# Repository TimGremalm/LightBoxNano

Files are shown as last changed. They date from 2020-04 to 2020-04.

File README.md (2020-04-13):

# LightBoxNano
a generic LED controller that can be populated for either RGBW LED strip or addressable LED strip like WS2812.

It has the option for populating a pair of potentiometer, and a 5 way slider switch for controlling light modes.

An Arduino Nano is mounted using ordinary 2.54mm pitch pin headers.
Optionally a ESP32 Pico Kit can be mounted instead of the Nano, this is much more expensive it is a more powerful MCU and have WiFi.

A RS485 receiver and a pair of XLR connectors can also transform the LED controller into a DMX driver.

# Power Supply and voltage rails
## Input rail
The input voltage to LightBoxNano are called VIN and can range from 5 to 30V.
Make sure to only feed LightBoxNano with a voltage that the LED strip can handle. The maximum voltage is limited by the maximum voltage of the IRLML6344 Mosfets and of what the LED strip can handle.

If using 5V on Vin you need to read "Logic rail" to populate it correctly.

## RGBW rail
The positive rail for the LED strip driver is directly fed from VIN, it's usually 12V.

## Addressable rail
The positive rail for the addressable LED strip driver is directly fed from VIN, it's usually 5V.

## Logic rail
The logic rail should be 5V and feed the micro controller.

There is 2 options for the logic rail:
* Use buck, when Vin is greater than 5.5V.
* Use direct jumper link when Vin is 5V.

Note that the logic rail bypasses Vin_fused.

The buck converter using TI's guide:
https://webench.ti.com/power-designer/switching-regulator/select

https://webench.ti.com/appinfo/webench/scripts/SDP.cgi?ID=572687AF787DDED1

## Protection circuit
There is 2 options for input protection:
* A classic fuse
* Highside High Current Power Switch

### Classic Fuse
A much cheaper option then the high side switch, but one time use only.
Populate with a  appropriate 1206 fast blow fuse.
Example: Fuse Fast Blow 10A 1206 MCCFB1206TFF/10

No reverse polarity protection exist when using a classic fuse.

### Highside High Current Power Switch
The Infineon BTS50055-1TMC is a highside high current power switch with buildt in reverse
polarity and temperature protection.

It's also used to measure current consumption; Current_Feedback as analog output.
To enable the high power switch Enable_Vin_fused must be driven low.

Both Current_Feedback and Enable_Vin_fused goes to the MCU so it can act on over current
and act as a resettable fuse.

Vin_fused
| Channel			| Arduino Nano		| ESP32 |
| --- | --- | ----- |
| Current_Feedback	| A0 (PC0)			| IO38	|
| Enable_Vin_fused	| D13 (PB5)			| IO37	|

# RGBW driver
This is made for LED strip that have red, green, blue and white channels that have a common positive rail like +12V.
The LED driver can drive 4 output channels in constant voltage mode at 5A each. The channel can drive up to 10A current if an optional IRLML6344 is mounted.
One color channel on a 5m LED strip consisting of 300 LED's will draw 6A (20mA x 300px) when fully lit. A full RGB strip 18A, and a RGBW strip 24A.

| Channel	| Arduino Nano		| ESP32 |
| --- | --- | ----- |
| Red		| D5 (PD5)			| IO26	|
| Green		| D6 (PD6)			| IO27	|
| Blue		| D9 (PB1)			| IO13	|
| White		| D10 (PB2)			| IO15	|

# Addressable LED driver
Addressable LED strip is hooked up directly to VIN and the data pin is going to micro controller via a 1k resistor.

| Channel		| Arduino Nano		| ESP32 |
| --- | --- | ----- |
| Addressable	| D3 (PD3)			| IO25	|

# Control interface
Two potentiometers can optionally be mounted. They are pulled up to 3.3V, so you won't get the full range on the Nano.
| Channel	| Arduino Nano		| ESP32 |
| --- | --- | ----- |
| POT_1		| A1 (PC1)			| IO26	|
| POT_2		| A2 (PC2)			| IO27	|

A 10 position rotary coded switch can optionally be mounted for selecting different modes.
| Channel	| Arduino Nano		| ESP32 |
| --- | --- | ----- |
| SwCode1	| D7 (PD7)			| IO14	|
| SwCode2	| D8 (PB0)			| IO12	|
| SwCode4	| D11 (PB3)			| IO2	|
| SwCode8	| D12 (PB4)			| IO4	|

10 position switch is coded in binary.
| Code	| 0	| 1	| 2	| 3	| 4	| 5	| 6	| 7	| 8	| 9	|
| ----- | -	| -	| -	| -	| -	| -	| -	| -	| -	| -	|
| 1		| 	| *	| 	| *	| 	| *	| 	| *	| 	| *	|
| 2		| 	| 	| *	| *	| 	| 	| *	| *	| 	| 	|
| 4		| 	| 	| 	| 	| *	| *	| *	| *	| 	| 	|
| 8		| 	| 	| 	| 	| 	| 	| 	| 	| *	| *	|

Also a pin header of the Arduino Nano will be easily assessable for hooking up random stuff.

# DMX Tranceiver
A RS-485 transceiver can optionally be mounted for sending and receiveing DMX512.
It uses ADM2687E which isolates the RS-485 bus from the low voltage micro controller side. This is important as electrical errors down the bus can propagage along the bus.
ADM2687E also isolates the power on the bus side by a buildt in DC to DC converter.

The tranceiver can be set to send DMX data if the jumper links "Link_DriverOutputA1" and "Link_DriverOutputB1" is soldered.

| Jumper							| Description													|
| --- | ---	|
| Link_DriverOutputA1				| Links the Z (Driver Inverting Output) to DMX+					|
| Link_DriverOutputB1				| Links the Y (Driver Noninverting Output) to DMX-				|
| Receiver_Disable1					| Pulls RE (Receiver Enable) to High which disables receiver	|
| Receiver_Enable1					| Pulls RE (Receiver Enable) to Low which enables receiver		|
| Driver_Enable1					| Pulls DE (Driver Enable) to High which enables sender			|
| Driver_Disable1					| Pulls DE (Driver Enable) to Low which disables sender			|
| Link_TransceiverGnd_To_DMXgnd1	| Links DMX bus Gnd to ADM2687E Gnd2							|
| Link_DMXgnd_To_DMXchassignd1		| Links DMX ground shield to ADM2687E Gnd2						|

DMX Send and Receive can be hooked up to UART channels on a MCU.
Receiver Enable and Driver Enable can also be driven by the micro controller (only ESP32).
| Channel			| Arduino Nano		| ESP32 |
| --- | --- | ----- |
| DMX_Send			| D1 TX (PD0)		| IO21	|
| DMX_Receive		| D0 RX (PD1)		| IO22	|
| DMX_ReceiveEnable	| N.C				| IO19	|
| DMX_DriveEnable	| N.C				| IO23	|

# MCU
An Arduino Nano V3 (ATmega328) is selected because it's cheap, available and have enough power for most applications.

Another option is to mount a ESP32 Pico Kit instead which is much more powerful and have built in WiFi.

# BOM (Bill Of Material)
| Amount	| Manufacturer		| Description										| Article Number		| URL																									|
| --- | --- | ---	| --- | --- |
| 1			| Arduino			| MCU Arduino Nano 3 ATmega328						| A000005				| https://se.farnell.com/arduino-org/a000005/arduino-nano-utv-rd-kort/dp/1848691						|
| 1			| Espressif			| MCU ESP32 Pico Kit V4								| ESP32-PICO-KIT		| https://www.digikey.com/product-detail/en/espressif-systems/ESP32-PICO-KIT/1904-1030-ND/9381703		|
| 8			| Infineon			| Mosfet N-Ch 5A SOT-23								| IRLML6344TRPBF		| https://se.farnell.com/infineon/irlml6344trpbf/mosfet-n-kan-30v-5a-sot23/dp/1857299					|
| 1			| Infineon			| Highside High Current Power Switch 34V 17A 6.0 mΩ	| BTS500551TMCATMA1		| https://se.farnell.com/infineon/bts500551tmcatma1/effektbelastning-h-s-34v-to-220/dp/2480566			|
| 1			| Analog Devices	| RS485 Transceiver Isolated						| ADM2687EBRIZ			| https://se.farnell.com/analog-devices/adm2687ebriz/transceiver-iso-rs485-16soic/dp/2008784			|
| 1			| Multicomp			| Fuse Fast Blow 10A 1206							| MCCFB1206TFF/10		| https://se.farnell.com/multicomp/mccfb1206tff-10/s-kring-ytmont-10a-snabb-1206/dp/2850011				|
| 1			| Littelfuse		| Schottky 200V 10A									| MBRD10200CT			| https://se.farnell.com/littelfuse/mbrd10200ct/schottky-rect-200v-10a-to-252/dp/2773825				|
| 1			| Nexperia			| ESD protection diode 5V 1.55pF					| PESD5V0X1UAB,115		| https://se.farnell.com/nexperia/pesd5v0x1uab-115/diode-esd-low-capacitance-sod523/dp/2069370			|
| 1			| Vishay-Dale		| Inductor 47µH 42.7mΩ								| IHLP6767GZER470M11	| https://se.farnell.com/vishay/ihlp6767gzer470m11/inductor-47uh-8-6a-20/dp/1845598						|
| 1			| Texas Instruments	| Buck 5V 3A										| LM2596SX-5.0/NOPB		| https://se.farnell.com/texas-instruments/lm2596sx-5-0-nopb/dc-dc-conv-buck-150khz-to-263/dp/2781829	|
| 1			| Kingbright		| LED Red 20mA 0603									| KP-1608SURCK			| https://se.farnell.com/kingbright/kp-1608surck/led-red-80mcd-630nm-smd/dp/2449786						|
| 2			| Multicomp			| Cap 10nF 50V 0603									| MCU0603R103KCT		| https://se.farnell.com/multicomp/mcu0603r103kct/cap-0-01-f-50v-10-x7r-0603/dp/9406182RL				|
| 4			| Multicomp			| Cap 100nF 16V 0603								| MC0603B104J160CT		| https://se.farnell.com/multicomp/mc0603b104j160ct/cap-0-1-f-16v-5-x7r-0603/dp/2320813					|
| 1			| AVX				| Cap 4.7µF 10V 1.4Ω 1206 Solid Electrolyte			| TPSA475K010R1400		| https://se.farnell.com/avx/tpsa475k010r1400/cap-4-7-f-10v-10-1206-smd/dp/1135104						|
| 2			| Taiyo Yuden		| Cap 10µF 10V 0603									| LMK107BBJ106MALT		| https://se.farnell.com/taiyo-yuden/lmk107bbj106malt/cap-10-f-10v-20-x5r-0603/dp/2113070				|
| 1			| Panasonic			| Cap 18µF 50V 35mΩ Aluminium Electrolytic			| 50SVPF18M				| https://se.farnell.com/panasonic/50svpf18m/cap-18-f-50v-20-radial/dp/2354813							|
| 1			| Kemet				| Cap 100µF 50V 27mΩ Aluminium Electrolytic			| A767MU107M1HLAE027	| https://se.farnell.com/kemet/a767mu107m1hlae027/kond-alu-polymer-100-f-50v-rad/dp/2614195RL			|
| 1			| Knitter-Switch	| Rotary Coded Switch 10 Position					| DRR4010				| https://se.farnell.com/knitter-switch/drr4010/rotary-switch-pcb-bcd/dp/807620							|
| 2			| Alps Alpine		| Pot 10k Linear									| 29 0001				| https://se.farnell.com/alps/29-0001/potentiometer-10k-20-0-05w/dp/1191735								|
| 1			| Multicomp			| Resistor 120R 0603								| MC0100W06031120R		| https://se.farnell.com/multicomp/mc0100w06031120r/motst-tjockfilm-120r-1-0-063w/dp/2845766			|
| 1			| Multicomp			| Resistor 300R 0603								| MC0100W06031300R		| https://se.farnell.com/multicomp/mc0100w06031300r/motst-tjockfilm-300r-1-0-063w/dp/2845860			|
| 8			| Multicomp			| Resistor 1k 0603									| MC0100W060311K		| https://se.farnell.com/multicomp/mc0100w060311k/motst-tjockfilm-1k-1-0-063w-0603/dp/2845750			|
| 8			| Multicomp			| Resistor 10k 0603									| MC0100W0603110K		| https://se.farnell.com/multicomp/mc0100w0603110k/motst-tjockfilm-10k-1-0-063w-0603/dp/2845751			|
| 1			| Neutrik			| XLR 3-pole female Horizontal PCB mount			| NC3FAAH2				| https://se.farnell.com/neutrik/nc3faah2/socket-xlr-pcb-horizontal-3pole/dp/1310023					|
| 1			| Neutrik			| XLR 3-pole male Horizontal PCB mount				| NC3MAAH				| https://se.farnell.com/neutrik/nc3maah/plug-xlr-pcb-horizontal-3pole/dp/1310044						|
| 1			| Phoenix Contact	| Connector Male 2 pin MSTBA 2,5/ 2-G-5,08			| 1757242				| https://se.farnell.com/phoenix-contact/1757242/header-right-angle-5-08mm-2way/dp/3705171				|
| 1			| Phoenix Contact	| Connector Male 3 pin MSTBA 2,5/ 3-G-5,08			| 1757255				| https://se.farnell.com/phoenix-contact/1757255/connector-header-tht-ra-5-08mm/dp/3705183				|
| 1			| Phoenix Contact	| Connector Male 5 pin MSTBA 2,5/ 5-G-5,08			| 1757271				| https://se.farnell.com/phoenix-contact/1757271/header-right-angle-5-08mm-5way/dp/3705201				|
| 1			| Phoenix Contact	| Connector Female 2 pin MSTB 2,5/ 2-ST-5,08		| 1757019				| https://se.farnell.com/phoenix-contact/1757019/terminal-block-pluggable-2pos/dp/3705353				|
| 1			| Phoenix Contact	| Connector Female 3 pin MSTB 2,5/ 3-ST-5,08		| 1757022				| https://se.farnell.com/phoenix-contact/mstb2-5-3-st-5-08/terminal-block-pluggable-3pos/dp/3705365		|
| 1			| Phoenix Contact	| Connector Female 5 pin MSTB 2,5/ 5-ST-5,08		| 1757048				| https://se.farnell.com/phoenix-contact/1757048/terminal-block-pluggable-5pos/dp/3705389				|
| 1			| Multicomp			| Barrel Jack Switch 5A 2mm							| SPC21364				| https://se.farnell.com/multicomp/spc21364/connector-power/dp/1654842									|
| 1			| Multicomp			| Enclosure 120x120x60mm ABS IP65					| MC001076				| https://se.farnell.com/multicomp/mc001076/l-da-ip65-abs-gr-/dp/2544917								|

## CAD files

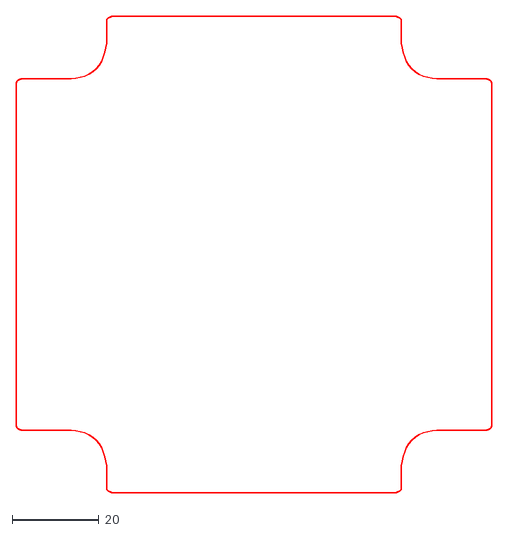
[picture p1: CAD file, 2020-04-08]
datasheets/Multicomp-MC001076_Enclosure_120x120x60mm_ABS_IP65_Inside.dxf
109.8 x 109.9

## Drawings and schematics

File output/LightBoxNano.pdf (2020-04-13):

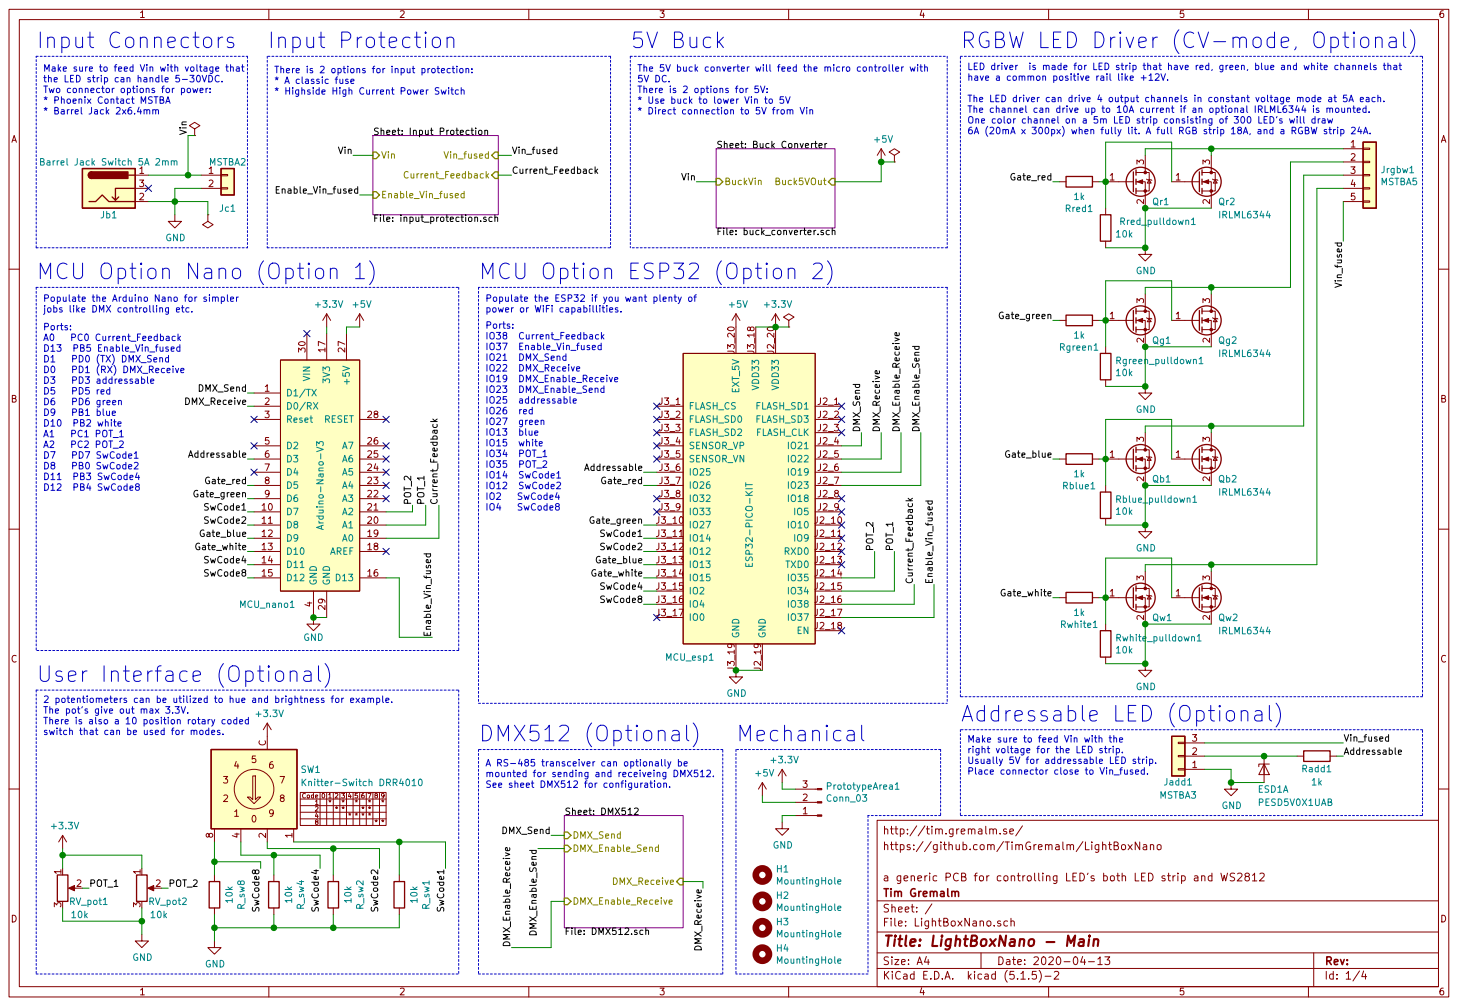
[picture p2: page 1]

Make sure to feed Vin with voltage that
the LED strip can handle 5-30VDC.
Two connector options for power: * Phoenix Contact MSTBA

There is 2 options for input protection: * A classic fuse

The 5V buck converter will feed the micro controller with
5V DC. There is 2 options for 5V: * Use buck to lower Vin to 5V

LED driver is made for LED strip that have red, green, blue and white channels that
have a common positive rail like +12V.

* Highside High Current Power Switch

The LED driver can drive 4 output channels in constant voltage mode at 5A each.
The channel can drive up to 10A current if an optional IRLML6344 is mounted.
One color channel on a 5m LED strip consisting of 300 LED's will draw
6A (20mA x 300px) when fully lit. A full RGB strip 18A, and a RGBW strip 24A.

* Direct connection to 5V from Vin

MCU Option Nano (Option 1)

Populate the Arduino Nano for simpler
jobs like DMX controlling etc.
Ports: A0 PC0 Current_Feedback D13 PB5 Enable_Vin_fused D1 PD0 (TX) DMX_Send

2 potentiometers can be utilized to hue and brightness for example.
The pot's give out max 3.3V.
There is also a 10 position rotary coded
switch that can be used for modes.

right voltage for the LED strip.
Usually 5V for addressable LED strip. Place connector close to Vin_fused.

mounted for sending and receiveing DMX512.
See sheet DMX512 for configuration.

http://tim.gremalm.se/ Sheet: DMX512 File: DMX512.sch DMX_SendDMX_Receive DMX_Enable_Receive DMX_Enable_Send

https://github.com/TimGremalm/LightBoxNano

a generic PCB for controlling LED's both LED strip and WS2812
File: LightBoxNano.sch Sheet: / Tim Gremalm

Id: 1/4 Title: LightBoxNano - Main

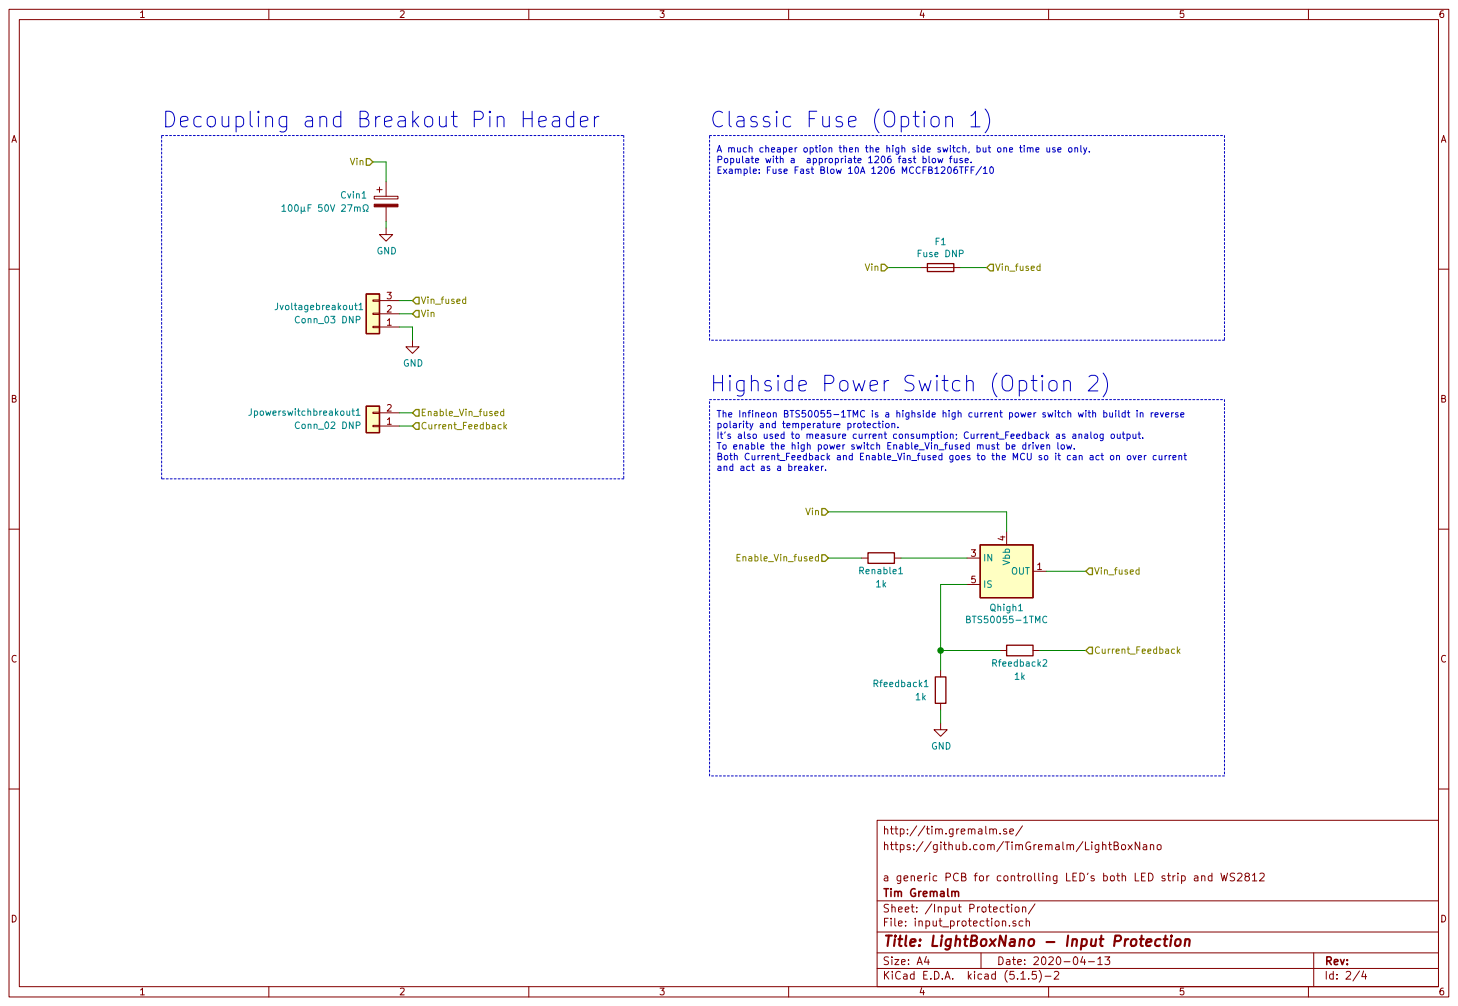
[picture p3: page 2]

Both Current_Feedback and Enable_Vin_fused goes to the MCU so it can act on over current and act as a breaker. Classic Fuse (Option 1)

A much cheaper option then the high side switch, but one time use only.
Populate with a appropriate 1206 fast blow fuse.
Example: Fuse Fast Blow 10A 1206 MCCFB1206TFF/10

http://tim.gremalm.se/ GND

Highside Power Switch (Option 2)

The Infineon BTS50055-1TMC is a highside high current power switch with buildt in reverse
polarity and temperature protection.
It's also used to measure current consumption; Current_Feedback as analog output.
To enable the high power switch Enable_Vin_fused must be driven low.

https://github.com/TimGremalm/LightBoxNano

a generic PCB for controlling LED's both LED strip and WS2812
Sheet: /Input Protection/ Tim Gremalm

File: input_protection.sch
Id: 2/4 Title: LightBoxNano - Input Protection

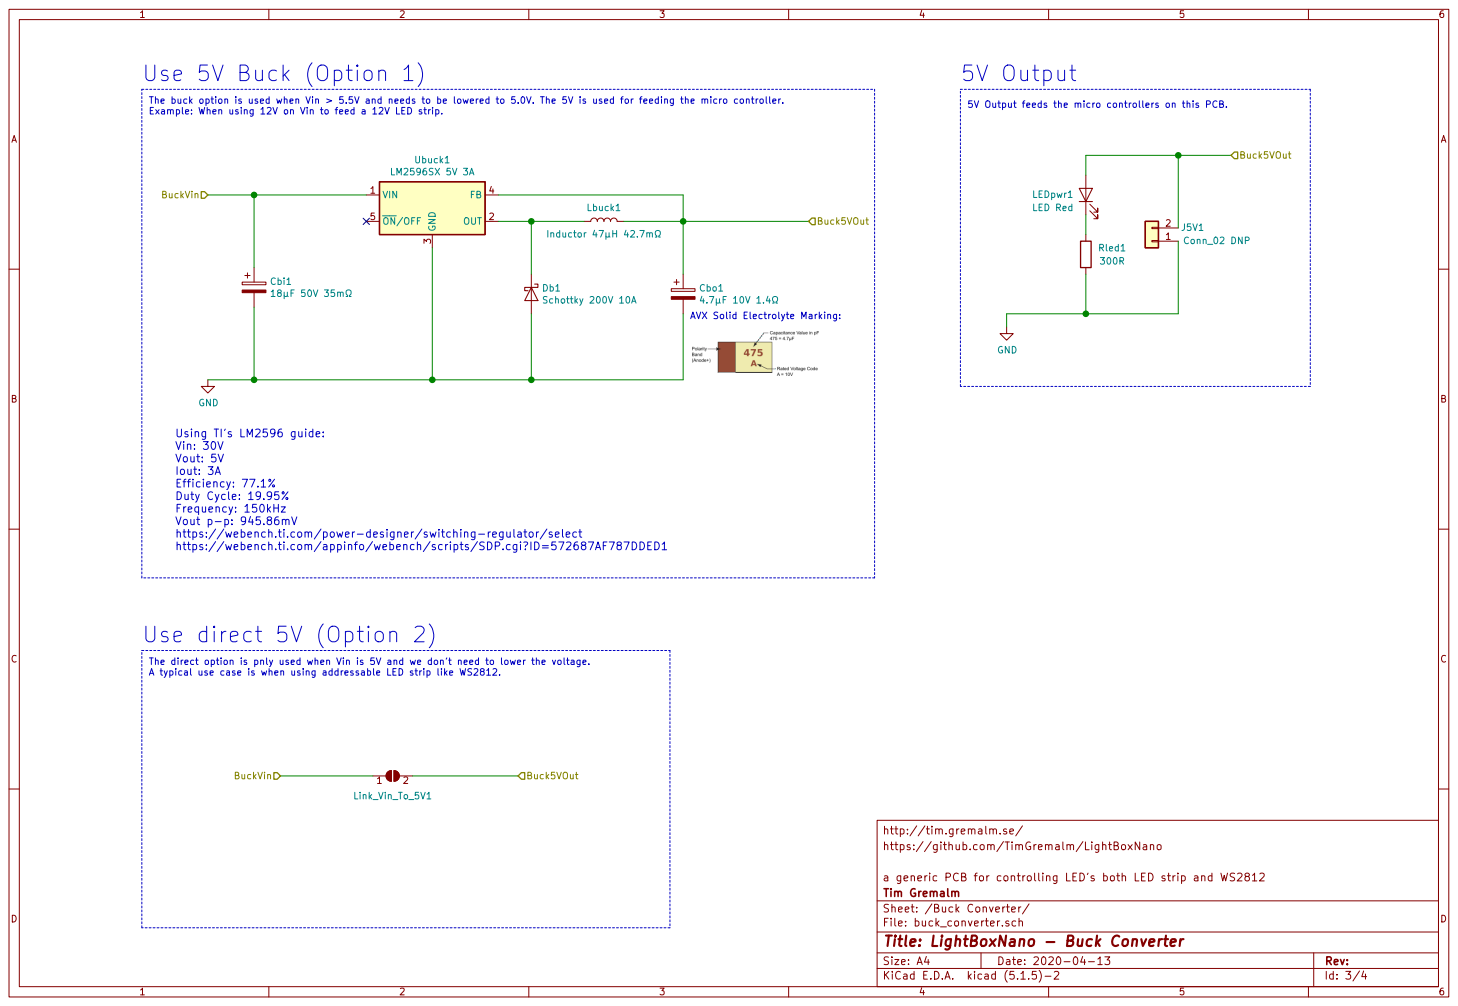
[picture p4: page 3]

Buck5VOut The buck option is used when Vin > 5.5V and needs to be lowered to 5.0V. The 5V is used for feeding the micro controller.
Example: When using 12V on Vin to feed a 12V LED strip.

5V Output feeds the micro controllers on this PCB.

AVX Solid Electrolyte Marking:

Using TI's LM2596 guide: Vin: 30V

Vout: 5V
Iout: 3A
Efficiency: 77.1%
Duty Cycle: 19.95%
Frequency: 150kHz
Vout p-p: 945.86mV
https://webench.ti.com/power-designer/switching-regulator/select
https://webench.ti.com/appinfo/webench/scripts/SDP.cgi?ID=572687AF787DDED1

The direct option is pnly used when Vin is 5V and we don't need to lower the voltage.
A typical use case is when using addressable LED strip like WS2812.

http://tim.gremalm.se/
https://github.com/TimGremalm/LightBoxNano

a generic PCB for controlling LED's both LED strip and WS2812
File: buck_converter.sch Sheet: /Buck Converter/ Tim Gremalm

Id: 3/4 Title: LightBoxNano - Buck Converter

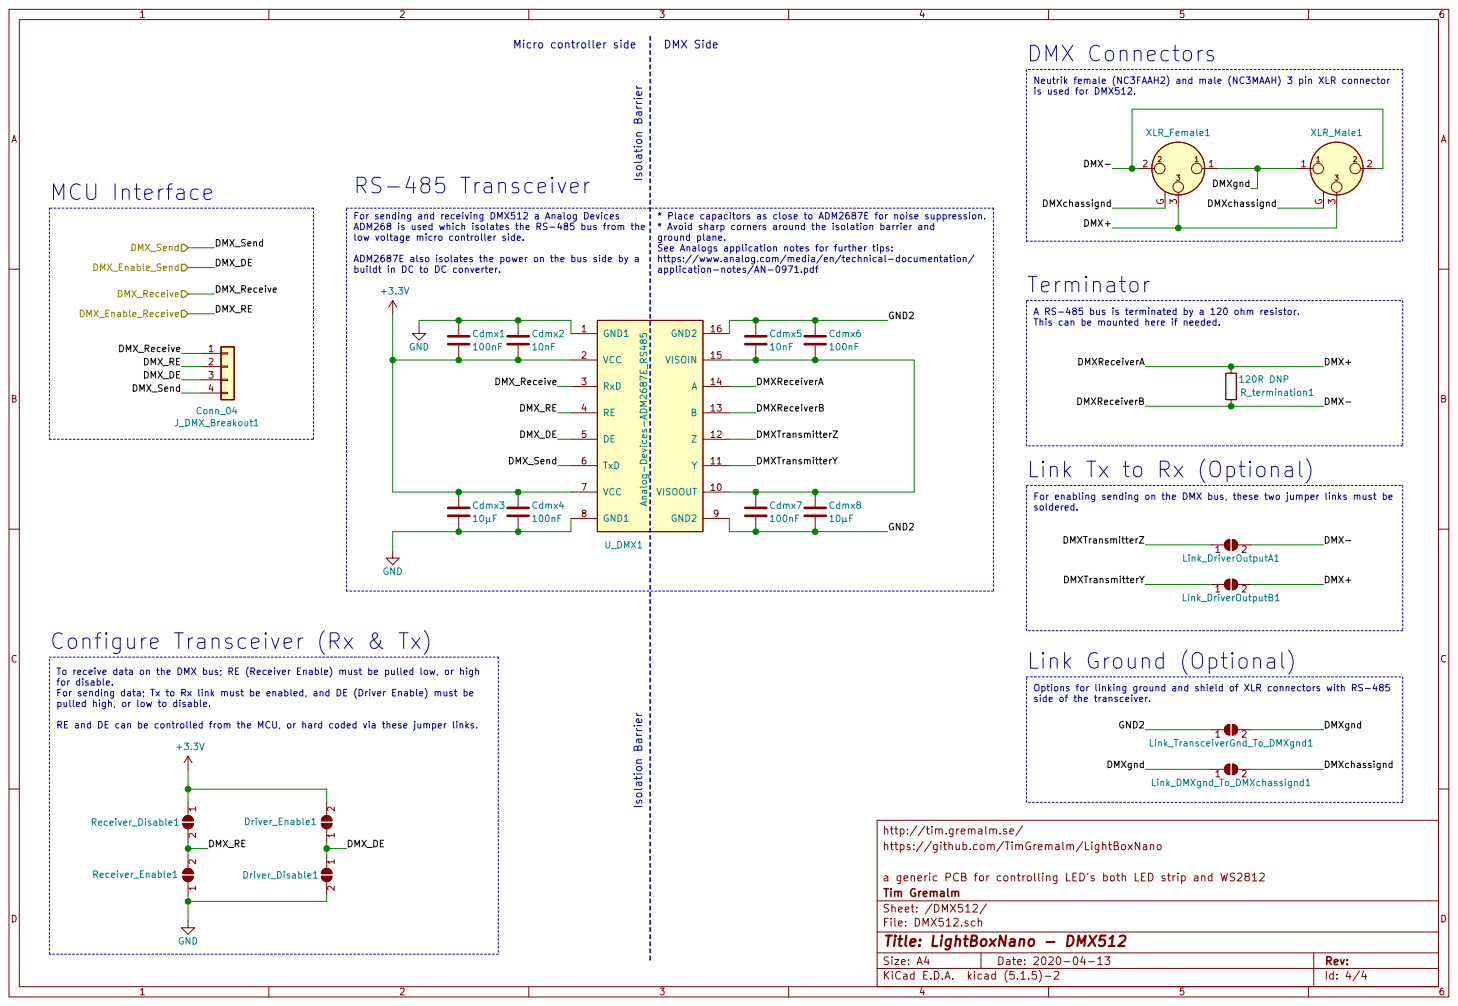
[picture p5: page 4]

is used for DMX512. Configure Transceiver (Rx & Tx)

A RS-485 bus is terminated by a 120 ohm resistor. This can be mounted here if needed. Isolation Barrier

For sending and receiving DMX512 a Analog Devices ADM268 is used which isolates the RS-485 bus from the

* Place capacitors as close to ADM2687E for noise suppression.
* Avoid sharp corners around the isolation barrier and
ground plane.
See Analogs application notes for further tips:
https://www.analog.com/media/en/technical-documentation/
application-notes/AN-0971.pdf

low voltage micro controller side.

ADM2687E also isolates the power on the bus side by a

side of the transceiver. For enabling sending on the DMX bus, these two jumper links must be

To receive data on the DMX bus; RE (Receiver Enable) must be pulled low, or high
for disable. For sending data; Tx to Rx link must be enabled, and DE (Driver Enable) must be
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

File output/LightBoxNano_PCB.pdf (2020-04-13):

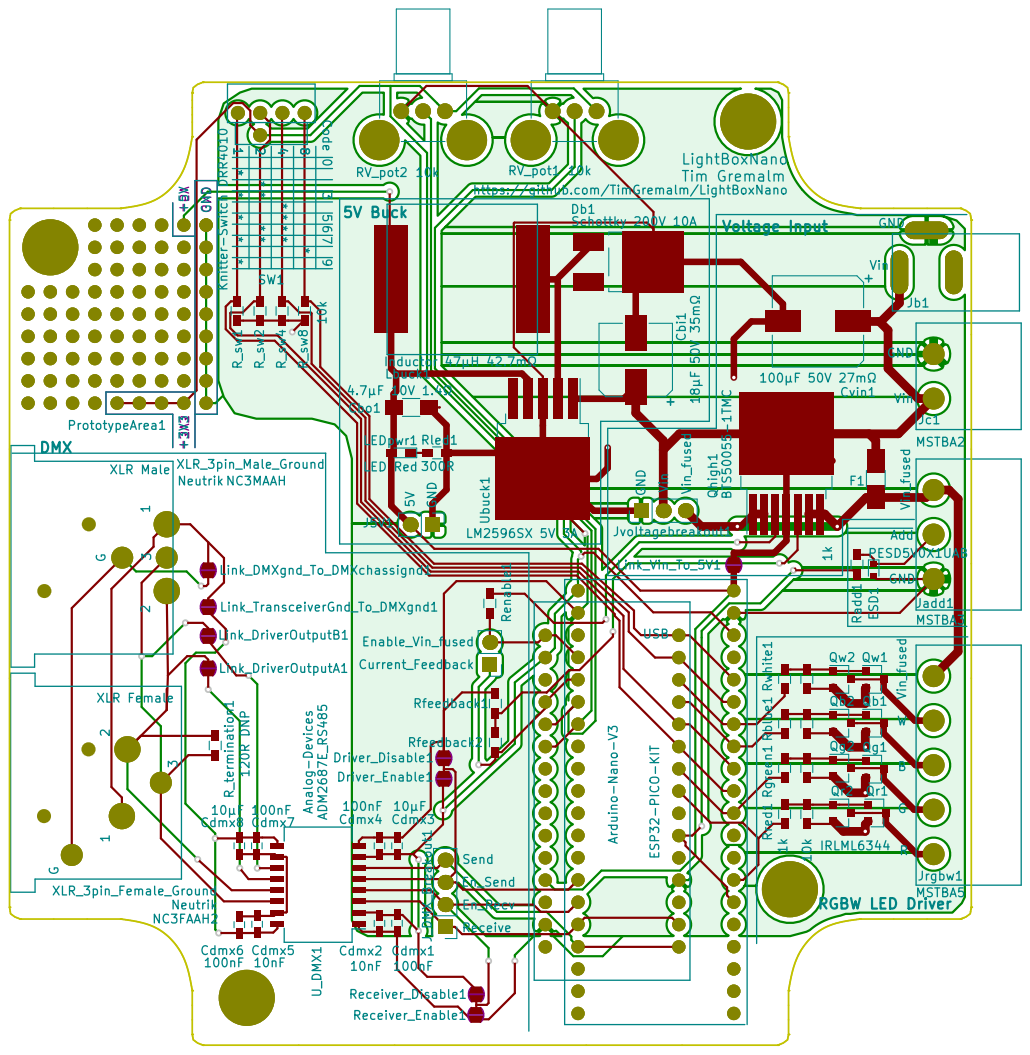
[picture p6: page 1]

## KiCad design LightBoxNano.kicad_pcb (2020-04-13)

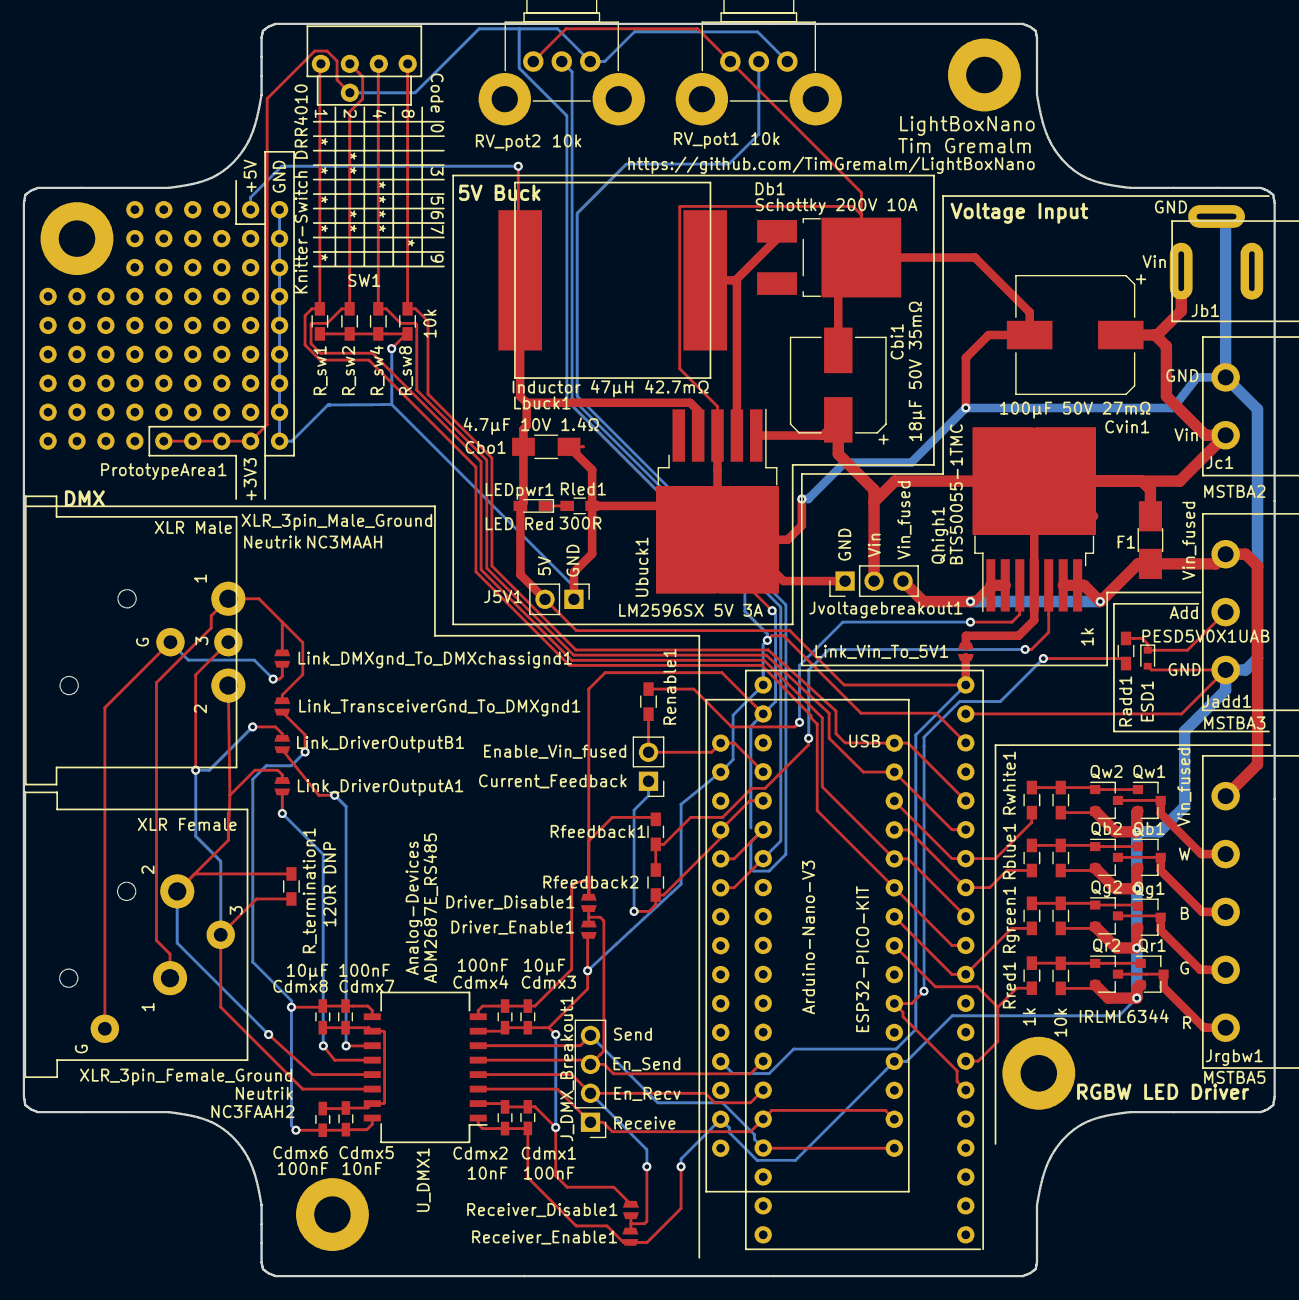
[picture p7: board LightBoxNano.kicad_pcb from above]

Board: 2 copper layers, 109.8 x 109.9 mm, 74 parts (0 on the bottom side), 43 nets.

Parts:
Cbi1: 18µF 50V 35mΩ; CP_Elec_8x10
Cbo1: 4.7µF 10V 1.4Ω; C_1206_HandSoldering
Cdmx1, Cdmx4, Cdmx6, Cdmx7: 100nF; C_0603_HandSoldering
Cdmx2, Cdmx5: 10nF; C_0603_HandSoldering
Cdmx3, Cdmx8: 10µF; C_0603_HandSoldering
Cvin1: 100µF 50V 27mΩ; CP_Elec_10x10.5
Db1: Schottky 200V 10A; TO-252-2_Rectifier
Driver_Disable1: DriverEnable; JUMPER-SOLDER-SMD
Driver_Enable1: DriverEnable; JUMPER-SOLDER-SMD
ESD1: PESD5V0X1UAB; D_SOD-523
F1: Fuse DNP; Fuse_SMD1206_HandSoldering
H1, H2, H3, H4: MountingHole; MountingHole_3.2mm_M3_Pad
J5V1: Conn_02 DNP; Pin_Header_Straight_1x02_Pitch2.54mm
J_DMX_Breakout1: Conn_04; Pin_Header_Straight_1x04_Pitch2.54mm
Jadd1: MSTBA3; PhoenixContact-MSTBA_2,5_4-G-5,08_3pole
Jb1: Barrel Jack Switch 5A 2mm; BarrelJack_SPC21364
Jc1: MSTBA2; PhoenixContact-MSTBA_2,5_4-G-5,08_2pole
Jpowerswitchbreakout1: Conn_02 DNP; Pin_Header_Straight_1x02_Pitch2.54mm
Jrgbw1: MSTBA5; PhoenixContact-MSTBA_2,5_4-G-5,08_5pole
Jvoltagebreakout1: Conn_03 DNP; Pin_Header_Straight_1x03_Pitch2.54mm
LEDpwr1: LED Red; LED_0603_HandSoldering
Lbuck1: Inductor 47µH 42.7mΩ; Inductor_IHLP6767GZER470M11
Link_DMXgnd_To_DMXchassignd1: LinkDmxGndToChassiGnd; JUMPER-SOLDER-SMD
Link_DriverOutputA1: LinkDriverOutput; JUMPER-SOLDER-SMD
Link_DriverOutputB1: LinkDriverOutput; JUMPER-SOLDER-SMD
Link_TransceiverGnd_To_DMXgnd1: LinkTransceiverGndToDmxGnd; JUMPER-SOLDER-SMD
Link_Vin_To_5V1: Link Vin to 5V; JUMPER-SOLDER-SMD
MCU_esp1: ESP32-PICO-KIT; ESP32-PICO-KIT_Jumper
MCU_nano1: Arduino-Nano-V3; Arduino-Nano-V3_Jumper
PrototypeArea1: Conn_03; PrototypeArea
Qb1, Qb2: IRLML6344; SOT-23
Qg1, Qg2: IRLML6344; SOT-23
Qhigh1: BTS50055-1TMC; TO-263-7_TabPin4
Qr1, Qr2: IRLML6344; SOT-23
Qw1, Qw2: IRLML6344; SOT-23
RV_pot1, RV_pot2: 10k; Potentiometer_Alps_RK09K_Vertical
R_sw1, R_sw2, R_sw4, R_sw8: 10k; R_0603_HandSoldering
R_termination1: 120R DNP; R_0603_HandSoldering
Radd1: 1k; R_0603_HandSoldering
Rblue1: 1k; R_0603_HandSoldering
Rblue_pulldown1: 10k; R_0603_HandSoldering
Receiver_Disable1: ReveiverEnable; JUMPER-SOLDER-SMD
Receiver_Enable1: ReceiverEnable; JUMPER-SOLDER-SMD
Renable1: 1k; R_0603_HandSoldering
Rfeedback1, Rfeedback2: 1k; R_0603_HandSoldering
Rgreen1: 1k; R_0603_HandSoldering
Rgreen_pulldown1: 10k; R_0603_HandSoldering
Rled1: 300R; R_0603_HandSoldering
Rred1: 1k; R_0603_HandSoldering
Rred_pulldown1: 10k; R_0603_HandSoldering
Rwhite1: 1k; R_0603_HandSoldering
Rwhite_pulldown1: 10k; R_0603_HandSoldering
SW1: Knitter-Switch DRR4010; DRR4010
U_DMX1: Analog-Devices-ADM2687E_RS485; SOIC-16W_7.5x12.8mm_Pitch1.27mm
Ubuck1: LM2596SX 5V 3A; TO-263-5_TabPin3
XLR_Female1: XLR_3pin_Female_Ground; XLR_3pole-female_Horizontal_PCB_mount_NC3FAAH2
XLR_Male1: XLR_3pin_Male_Ground; XLR_3pole-male_Horizontal_PCB_mount_NC3MAAH

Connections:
+3V3: Cdmx1.2, Cdmx2.2, Cdmx3.1, Cdmx4.1, Driver_Enable1.2, MCU_esp1.J2_20, MCU_esp1.J3_18, MCU_nano1.17, PrototypeArea1.3, RV_pot1.1, RV_pot2.1, Receiver_Disable1.1, SW1.C, U_DMX1.2, U_DMX1.7
+5V: Cbo1.1, J5V1.2, LEDpwr1.2, Lbuck1.2, Link_Vin_To_5V1.2, MCU_esp1.J3_20, MCU_nano1.27, PrototypeArea1.2, Ubuck1.4
/Addressable: MCU_esp1.J3_6, MCU_nano1.6, Radd1.2
/Current_Feedback: Jpowerswitchbreakout1.1, MCU_esp1.J2_16, MCU_nano1.19, Rfeedback2.2
/DMX512/DMX+: Link_DriverOutputB1.2, R_termination1.2, U_DMX1.14, XLR_Female1.3, XLR_Male1.3
/DMX512/DMX-: Link_DriverOutputA1.2, R_termination1.1, U_DMX1.13, XLR_Female1.2, XLR_Male1.2
/DMX512/DMXTransmitterY: Link_DriverOutputB1.1, U_DMX1.11
/DMX512/DMXTransmitterZ: Link_DriverOutputA1.1, U_DMX1.12
/DMX512/DMXchassignd: Link_DMXgnd_To_DMXchassignd1.2, XLR_Female1.G, XLR_Male1.G
/DMX512/DMXgnd: Link_DMXgnd_To_DMXchassignd1.1, Link_TransceiverGnd_To_DMXgnd1.2, XLR_Female1.1, XLR_Male1.1
/DMX512/GND2: Cdmx5.1, Cdmx6.1, Cdmx7.2, Cdmx8.2, Link_TransceiverGnd_To_DMXgnd1.1, U_DMX1.9, U_DMX1.16
/DMX_Enable_Receive: J_DMX_Breakout1.2, MCU_esp1.J2_6, Receiver_Disable1.2, Receiver_Enable1.2, U_DMX1.4
/DMX_Enable_Send: Driver_Disable1.1, Driver_Enable1.1, J_DMX_Breakout1.3, MCU_esp1.J2_7, U_DMX1.5
/DMX_Receive: J_DMX_Breakout1.1, MCU_esp1.J2_5, MCU_nano1.2, U_DMX1.3
/DMX_Send: J_DMX_Breakout1.4, MCU_esp1.J2_4, MCU_nano1.1, U_DMX1.6
/Enable_Vin_fused: Jpowerswitchbreakout1.2, MCU_esp1.J2_17, MCU_nano1.16, Renable1.1
/Gate_blue: MCU_esp1.J3_13, MCU_nano1.12, Rblue1.1
/Gate_green: MCU_esp1.J3_10, MCU_nano1.9, Rgreen1.1
/Gate_red: MCU_esp1.J3_7, MCU_nano1.8, Rred1.1
/Gate_white: MCU_esp1.J3_14, MCU_nano1.13, Rwhite1.1
/POT_1: MCU_esp1.J2_15, MCU_nano1.20, RV_pot1.2
/POT_2: MCU_esp1.J2_14, MCU_nano1.21, RV_pot2.2
/SwCode1: MCU_esp1.J3_11, MCU_nano1.10, R_sw1.2, SW1.1
/SwCode2: MCU_esp1.J3_12, MCU_nano1.11, R_sw2.2, SW1.2
/SwCode4: MCU_esp1.J3_15, MCU_nano1.14, R_sw4.2, SW1.4
/SwCode8: MCU_esp1.J3_16, MCU_nano1.15, R_sw8.2, SW1.8
/Vin: Cbi1.1, Cvin1.1, F1.2, Jb1.1, Jc1.1, Jvoltagebreakout1.2, Link_Vin_To_5V1.1, Qhigh1.4, Ubuck1.1
/Vin_fused: F1.1, Jadd1.3, Jrgbw1.5, Jvoltagebreakout1.3, Qhigh1.1, Qhigh1.2, Qhigh1.6, Qhigh1.7
GND: Cbi1.2, Cbo1.2, Cdmx1.1, Cdmx2.1, Cdmx3.2, Cdmx4.2, Cvin1.2, Db1.2, Driver_Disable1.2, ESD1.2, J5V1.1, Jadd1.1, Jb1.2, Jc1.2, Jvoltagebreakout1.1, MCU_esp1.J2_19, MCU_esp1.J3_19, MCU_nano1.4, MCU_nano1.29, PrototypeArea1.1, Qb1.2, Qb2.2, Qg1.2, Qg2.2, Qr1.2, Qr2.2, Qw1.2, Qw2.2, RV_pot1.3, RV_pot2.3, R_sw1.1, R_sw2.1, R_sw4.1, R_sw8.1, Rblue_pulldown1.2, Receiver_Enable1.1, Rfeedback1.2, Rgreen_pulldown1.2, Rled1.2, Rred_pulldown1.2, Rwhite_pulldown1.2, U_DMX1.1, U_DMX1.8, Ubuck1.3
unnamed: Cdmx5.2, Cdmx6.2, Cdmx7.1, Cdmx8.1, U_DMX1.10, U_DMX1.15
unnamed: Db1.1, Lbuck1.1, Ubuck1.2
unnamed: ESD1.1, Jadd1.2, Radd1.1
unnamed: Jrgbw1.1, Qr1.3, Qr2.3
unnamed: Jrgbw1.2, Qg1.3, Qg2.3
unnamed: Jrgbw1.3, Qb1.3, Qb2.3
unnamed: Jrgbw1.4, Qw1.3, Qw2.3
unnamed: LEDpwr1.1, Rled1.1
unnamed: Qb1.1, Qb2.1, Rblue1.2, Rblue_pulldown1.1
unnamed: Qg1.1, Qg2.1, Rgreen1.2, Rgreen_pulldown1.1
unnamed: Qhigh1.3, Renable1.2
unnamed: Qhigh1.5, Rfeedback1.1, Rfeedback2.1
unnamed: Qr1.1, Qr2.1, Rred1.2, Rred_pulldown1.1
unnamed: Qw1.1, Qw2.1, Rwhite1.2, Rwhite_pulldown1.1

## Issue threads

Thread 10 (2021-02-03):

Replace ADM2687EBRIZ

TimGremalm, 2021-02-03:
ADM2687EBRIZ is not manufactured anymore, replace with a common RS485 transceiver and isolate it.

Possible replacements:
* RS485 transceiver MAX485EESA+ https://se.farnell.com/maxim-integrated-products/max485eesa/transceiver-rs485-422-2-5mbps/dp/2518832
* Optocoupler FOD817BSD https://se.farnell.com/on-semiconductor/fod817bsd/optocoupler-transistor-5kv-smdip/dp/2985527
* Isolated DC to DC IL0505S https://se.farnell.com/xp-power/il0505s/converter-dc-dc-2w-5v/dp/8728097

goran-mahovlic, 2021-02-13:
This one could be option - but it would require additional isolated power circuit...

https://hr.mouser.com/ProductDetail/Texas-Instruments/ISO3086TDWR/?qs=wqKrPCMdR%252BYjX1VTdF3GRQ%3D%3D

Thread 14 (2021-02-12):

Firefly board

goran-mahovlic, 2021-02-12:
Hi,

just wanted to say thanks for sharing your board.
I needed to do some similar work.
And your designed help me a lot to design my version...

Not finished yet, but I think I will be over until end of the month.

https://github.com/intergalaktik/firefly

Goran

TimGremalm, 2021-02-12:
I'm glad the design could help you :)
Your Firefly is looking great! Also the blender rendering is gorgeous!

I've noticed that ADM2687EBRIZ is hard to get hold of, so I'm thinking of switching to another more common IC. I've created a issue regarding this here https://github.com/TimGremalm/LightBoxNano/issues/10

goran-mahovlic, 2021-02-12:
Tnx, and tnx again for providing me good starting point!

As I will soon need more then 50 boards - so for this batch I will switched to ADM2682EBRIZ that is more expansive, but should be the same.

goran-mahovlic, 2021-04-20:
My software is now up - still need to work on documentation

It is bit customized protocol - as I needed a way to address all LEDs on 40 panels individually with adding them to groups and control those groups.

https://github.com/intergalaktik/firefly_software

I managed to produce 40 pcs for museum, and now there is no more ADM chips :)
I have updated my repository with production photos.

I also added pass true software so now I can use USB -> DMX and control receiver from DMX software - currently I have tried Q light controller + and it is working great!

I also added FireFly to kitspace https://kitspace.org/boards/github.com/intergalaktik/firefly/

And now I ordered

NXJ1S1205MC-R7 and ISO3086TDWR

To give this combination a try, and if this would work then I could make some boards that I could share ...

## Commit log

2019-11-28 Schema Arduino Nano, Pots, Connectors
    [LightBoxNano.sch]
2019-11-28 Datasheet for Arduino Nano, Pots, Connectors
2019-11-28 Submodule kicad symbols and footprints
2019-11-28 Added BOM to readme
2019-11-28 BOM added N-channel mosfet IRLML6344
2019-11-28 Datasheet for IRLML6344 N-Channel mosfet
2019-11-29 Gitignore KiCad files
2019-11-29 Test to import on KiCad 5.1.5 on Windows 10
    [LightBoxNano.sch]
2019-11-29 Rough movement in schema
    [LightBoxNano.sch]
2019-11-29 Added project symbol IRLML6344 N-channel mosfet
2019-11-29 Schema added 5V buck, Wemos D1 ESP8266, Structure
    [LightBoxNano.sch, buck_converter.sch]
2019-11-29 Add resistor divider for POT connected to ESP8266
    [LightBoxNano.sch]
2019-11-29 Added RGBW LED driver to schema
    [LightBoxNano.sch]
2019-11-29 Added 5-way position switch
    [LightBoxNano.sch]
2019-11-29 Added DMX block to schema
    [LightBoxNano.sch, buck_converter.sch]
2019-11-29 Footprint and datasheets for components in buck
    [LightBoxNano.sch, buck_converter.sch]
2019-11-29 Footprint 0603 for resistors
    [LightBoxNano.sch]
2019-11-30 Datasheet for resistors in schema
    [LightBoxNano.sch]
2019-11-30 Automatic annotation
    [LightBoxNano.sch, buck_converter.sch]
2019-11-30 Removed submodule KiCad libs, it's included in V5
    [LightBoxNano.sch]
2019-11-30 Footprint for Barrel Jack Connector
    [LightBoxNano.sch]
2019-11-30 Added link to IRLML6344 Mosfet's in schema
    [LightBoxNano.sch]
2019-11-30 Change BOM link to IRLML6344 to a non reel
    [LightBoxNano.sch]
2019-11-30 Links and info about MCU's
    [LightBoxNano.sch]
2019-11-30 WeMos D1 to BOM
2019-11-30 Update BOM
2019-11-30 Schema details
    [LightBoxNano.sch, buck_converter.sch]
2019-12-02 Added adressable and RGBW to MCU nano
    [LightBoxNano.sch, buck_converter.sch]
2020-04-02 ESP32-PICO-KIT V4 Footprint and Symbol
2020-04-02 Arduino Nano V3 Footprint and Symbol
2020-04-02 Switched out ESP8266 for ESP32
    [LightBoxNano.sch]
2020-04-02 Schema connect ESP32
    [LightBoxNano.sch]
2020-04-02 Symbol Arduino Label Placement
2020-04-02 Symbol ESP32 Solid Box
2020-04-02 Schema smaller connection placement
    [LightBoxNano.sch, buck_converter.sch]
2020-04-02 Place Power on top and bottom in MCU symbol block
    [LightBoxNano.sch]
2020-04-02 Add PhoenixContact footprints, and set in schema
    [LightBoxNano.sch]
2020-04-03 Added DMX support via ADM2687E RS-485 Transiever
    [LightBoxNano.sch, buck_converter.sch]
2020-04-03 Added older 2.3 datasheet for Arduino Nano
2020-04-03 Add XLR connectors Amphenol AC3FAH
    [LightBoxNano.sch]
2020-04-03 Switched XLR to Neutrik-NC3FAAH2
    [LightBoxNano.sch]
2020-04-04 Footprint Neutrik XLR NC3FAAH2 NC3MAAH
    [LightBoxNano.sch]
2020-04-04 Switched Pots to Alps 29 0001
    [LightBoxNano.sch]
2020-04-04 Added Rotary Code Knitter-Switch DRR4010
    [LightBoxNano.sch]
2020-04-05 Schema sub sheet for DMX512 and description texts
    [DMX512.sch, LightBoxNano.sch, buck_converter.sch]
2020-04-05 Readme Control Interface
    [DMX512.sch]
2020-04-05 Schema Cleanup
    [DMX512.sch, LightBoxNano.sch]
2020-04-06 Update Capacitors for the RS-485 transceiver
    [DMX512.sch, LightBoxNano.sch, buck_converter.sch]
2020-04-06 Add power flags to outputs, fix validation errors
    [LightBoxNano.sch]
2020-04-06 Set correct footprint on caps belonging to ADM268
    [DMX512.sch]
2020-04-06 Rough PCB layout
    [DMX512.sch, LightBoxNano.kicad_pcb, LightBoxNano.sch]
2020-04-06 Nicer placment of labels and components on PCB
    [LightBoxNano.kicad_pcb, LightBoxNano.sch]
2020-04-06 Add 3mm mounting holes
    [LightBoxNano.kicad_pcb, LightBoxNano.sch]
2020-04-06 Add sub sheet for Input Protection
    [DMX512.sch, LightBoxNano.kicad_pcb, LightBoxNano.sch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]
2020-04-07 Add Input Protection, highside power switch, fuse
    [DMX512.sch, LightBoxNano.sch, buck_converter.sch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]
2020-04-07 Add Input Protection to PCB
    [LightBoxNano.kicad_pcb, LightBoxNano.sch]
2020-04-07 5V direct jumper link option for logic rail
    [LightBoxNano.sch, buck_converter.sch]
2020-04-08 Input Protection description, Pwer Switch Feedback
    [LightBoxNano.kicad_pcb, LightBoxNano.sch, buck_converter.sch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]
2020-04-08 Adjust PCB size to enclosure
    [LightBoxNano.kicad_pcb, Multicomp-MC001076_Enclosure_120x120x60mm_ABS_IP65_Inside.dxf]
2020-04-08 Start routing on PCB
    [LightBoxNano.kicad_pcb]
2020-04-08 Route PCB
    [LightBoxNano.kicad_pcb]
2020-04-08 Add labels to PCB, plot output
    [LightBoxNano-B_Cu.gbr, LightBoxNano-B_Mask.gbr, LightBoxNano-B_Paste.gbr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]
2020-04-10 Pretty labels on PCB
    [LightBoxNano-B_Cu.gbr, LightBoxNano-B_Mask.gbr, LightBoxNano-B_SilkS.gbr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]
2020-04-10 Smaller changes to labels on PCB
    [LightBoxNano.kicad_pcb, LightBoxNano.sch]
2020-04-10 Add solder prototype Area to PCB
    [LightBoxNano-B_Cu.gbr, LightBoxNano-B_Mask.gbr, LightBoxNano-B_SilkS.gbr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]
2020-04-13 Add ESD protection diode
    [LightBoxNano.kicad_pcb, LightBoxNano.sch, input_protection.sch]
2020-04-13 Add Led Alert logotype, layout
    [DMX512.sch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]

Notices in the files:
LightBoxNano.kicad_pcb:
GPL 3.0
